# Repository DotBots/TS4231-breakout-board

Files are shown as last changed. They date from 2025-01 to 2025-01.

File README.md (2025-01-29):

# TS4231-breakout-board
Kicad hardware files for a breakout board of the TS4231 lighthouse v2 receiver IC from Triad Semiconductors. 
The PCB was designed to be as small as possible, and expose the 2 data lines from the TS4231 as well as VCC and GND

<p align="center">
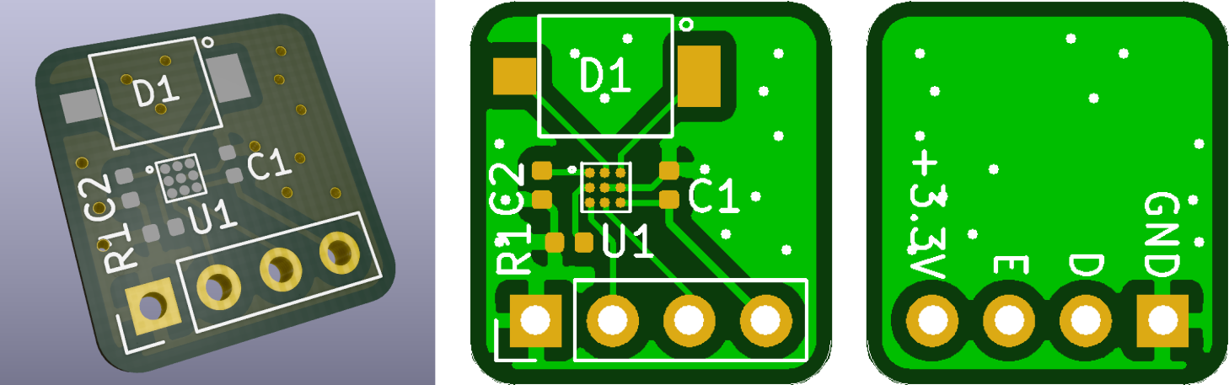
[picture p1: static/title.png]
    
</p>

## Schematic

The schematic was taken directly from the recommended circuit from the TS4231 datasheet.

<p align="center">
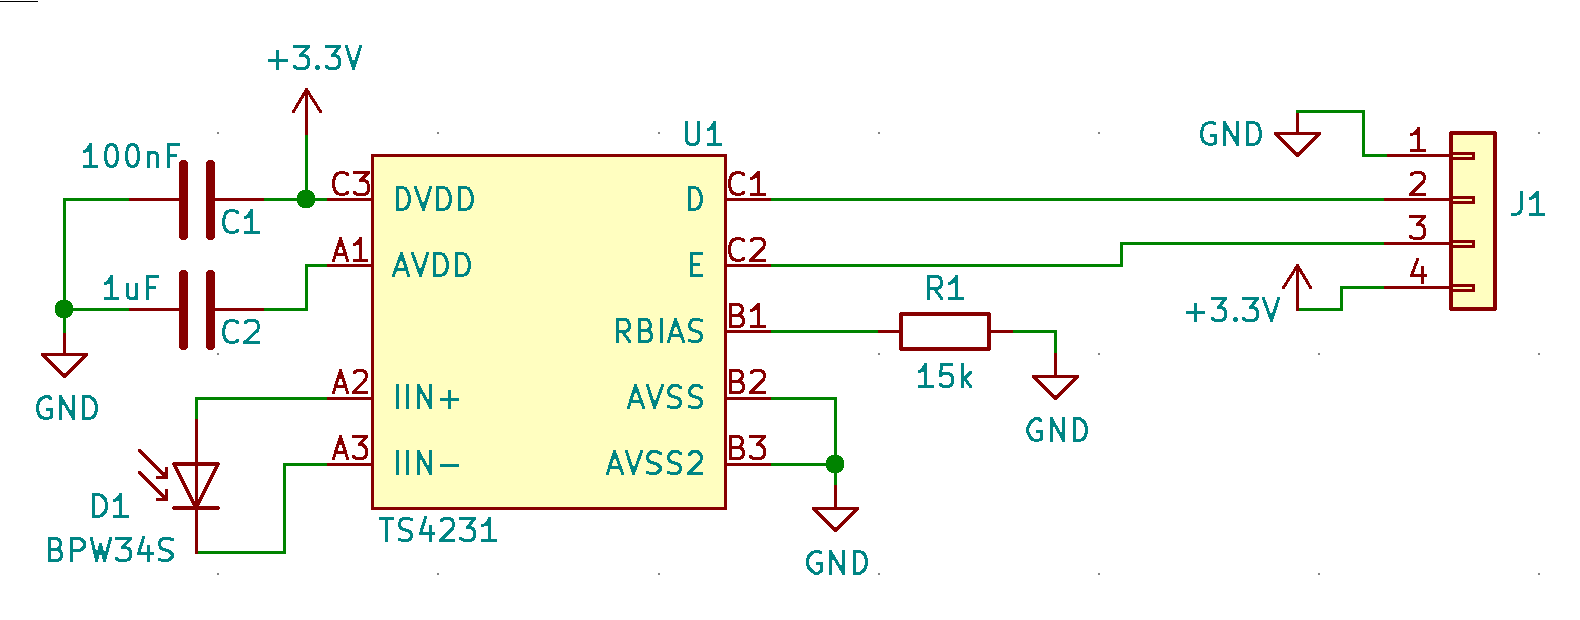
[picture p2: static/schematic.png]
    
</p>

## PCB

<p align="center">
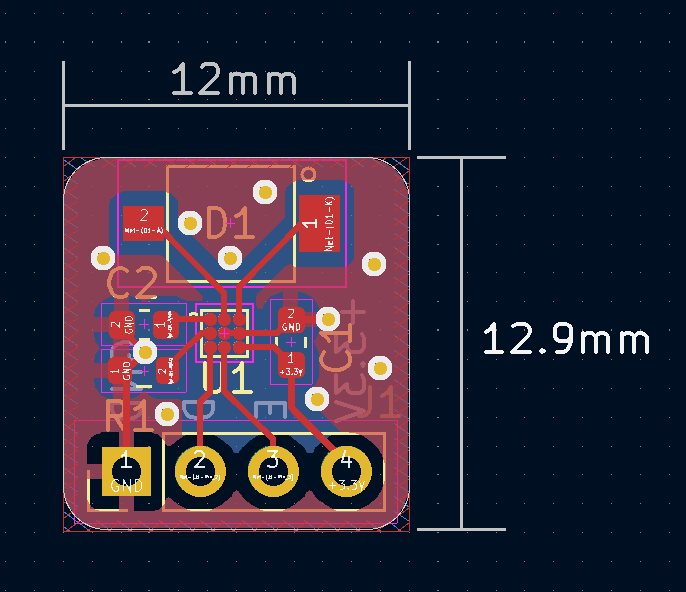
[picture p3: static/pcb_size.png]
    
</p>

## Bill of Materials
| Image | Function | Name | Quantity | Price per unit | Link |
|---|---|---|---|---|---|
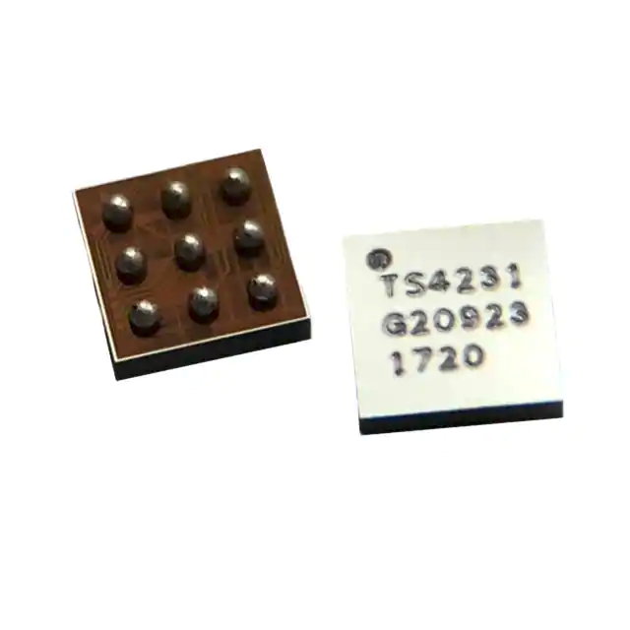
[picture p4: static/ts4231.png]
|  | Lighthouse Receiver IC | TS4231 | 1 | $2.37 | [Buy](https://www.digikey.com/short/7jnj8fr2) |
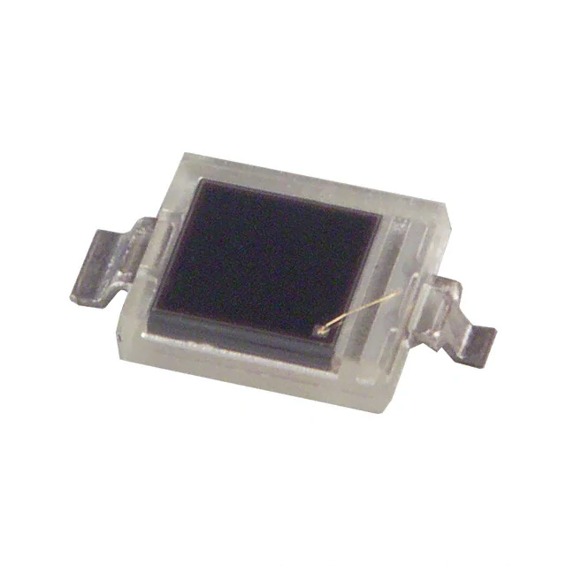
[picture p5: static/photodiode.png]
|  | Photodiode 850nm 20ns 120° 2-SMD, Gull Wing | BPW 34 S-Z | 1 | $1.33 | [Buy](https://www.digikey.com/short/jhrrf52v) |
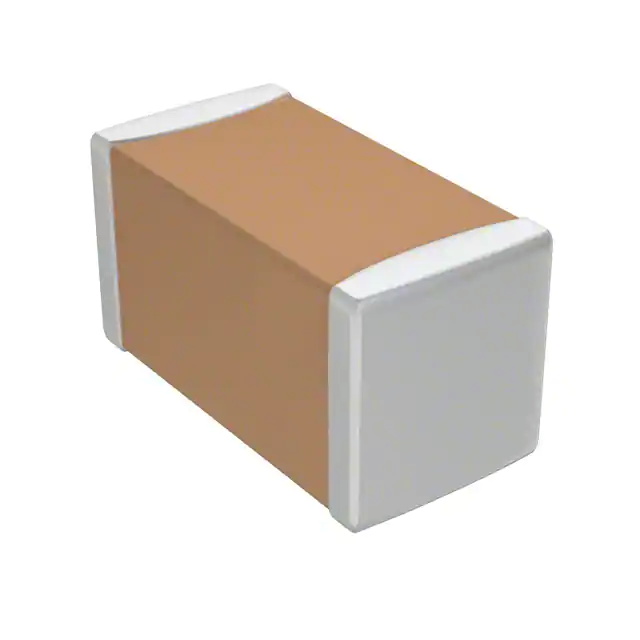
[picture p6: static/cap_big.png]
|  | 1 µF ±10% 16V Ceramic Capacitor X7R 0603 (1608 Metric) | CL10B105KO8NNNC | 1 | $0.1 | [Buy](https://www.digikey.com/short/j7tzj5fq) |
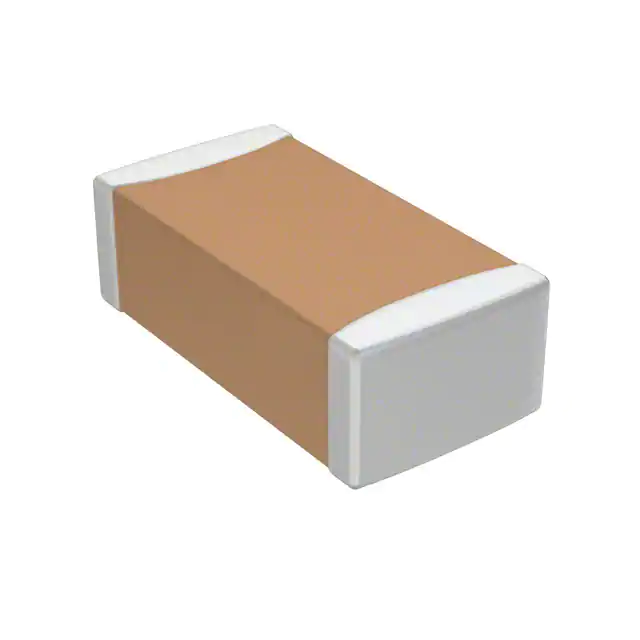
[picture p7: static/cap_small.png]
|   | 0.1 µF ±10% 16V Ceramic Capacitor X7R 0603 (1608 Metric) | CC0603KRX7R7BB104 | 1 | $0.1 | [Buy](https://www.digikey.com/short/vj2zz4q8) |
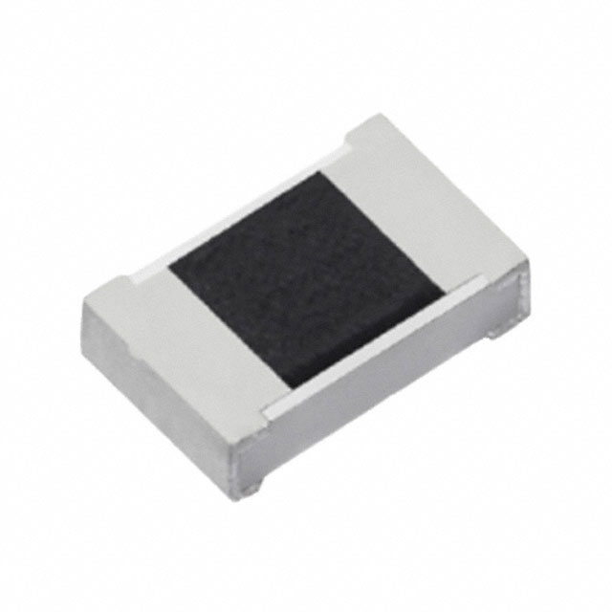
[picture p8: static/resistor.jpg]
|  | 15 kOhms ±1% 0.1W, 1/10W Chip Resistor 0603 (1608 Metric) | ERJ-3EKF1502V | 1 | $0.1 | [Buy](https://www.digikey.com/short/5w9hm2pj) |

Total cost of components per unit: $4.0

## References
- TS4231 Datasheet: [Link](https://www.digikey.com/en/htmldatasheets/production/5835669/0/0/1/ts4231)
- Similar PCB project: [Link](https://hackaday.io/project/19570-htc-vive-lighthouse-custom-tracking/log/146239-ts4231)

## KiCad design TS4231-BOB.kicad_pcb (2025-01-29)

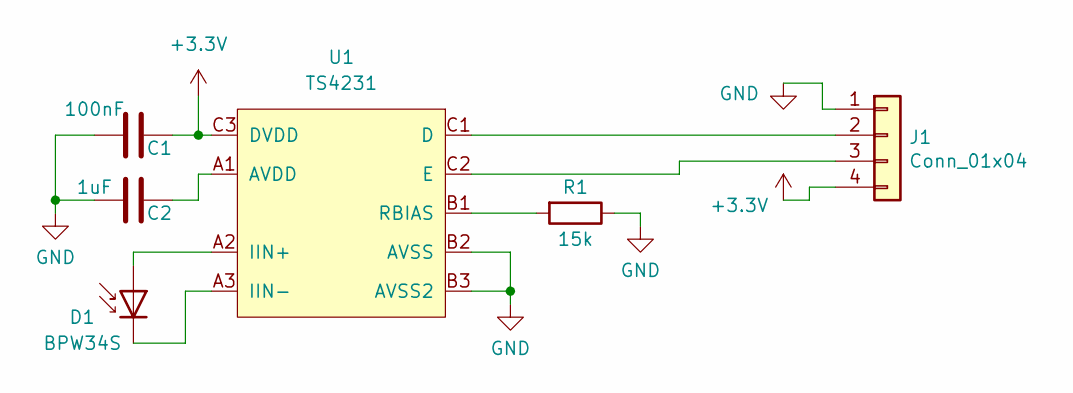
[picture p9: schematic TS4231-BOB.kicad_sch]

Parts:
C1: 100nF; C_0603_1608Metric; Mfr # CC0603KRX7R7BB104
C2: 1uF; C_0603_1608Metric; Mfr # CL10B105KO8NNNC
D1: BPW34S; BPW34; Mfr # BPW 34 S-Z
J1: Conn_01x04; PinHeader_1x04_P2.54mm_Vertical
R1: 15k; R_0603_1608Metric; Mfr # ERJ-3EKF1502V
U1: TS4231; Mfr # TS4231

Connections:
+3.3V: C1.1, J1.4, U1.C3 (DVDD)
GND: C1.2, C2.2, J1.1, R1.1, U1.B2 (AVSS), U1.B3 (AVSS2)
unnamed: D1.2 (A), U1.A2 (IIN+)
unnamed: D1.1 (K), U1.A3 (IIN-)
unnamed: J1.2, U1.C1 (D)
unnamed: J1.3, U1.C2 (E)
unnamed: C2.1, U1.A1 (AVDD)
unnamed: R1.2, U1.B1 (RBIAS)

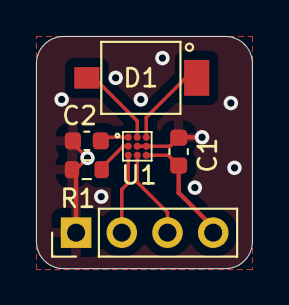
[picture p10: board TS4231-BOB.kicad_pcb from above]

Board: 2 copper layers, 12.0 x 12.9 mm, 6 parts (0 on the bottom side), 8 nets.

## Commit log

2025-01-29 add kicad project
    [TS4231-BOB.kicad_pcb, TS4231-BOB.kicad_sch]
2025-01-29 add gerber files
    [TS4231-BOB-B_Cu.gbl, TS4231-BOB-B_Mask.gbs, TS4231-BOB-B_Paste.gbp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]
2025-01-29 update BOM
    [TS4231-BOB.kicad_pcb, TS4231-BOB.kicad_sch]
